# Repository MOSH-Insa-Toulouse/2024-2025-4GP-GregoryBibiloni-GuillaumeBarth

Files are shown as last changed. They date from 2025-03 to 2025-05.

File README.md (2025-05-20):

# 2024-2025-4GP-GregoryBibiloni-GuillaumeBarth

## Projet Capteur Graphite

# Sommaire

- [Contexte](#contexte)
- [Livrables](#livrables)
- [Matériel necéssaire](#matériel-nécessaire)
- [Simulation LTSpice](#simulation-ltspice)
- [Design du PCB via KiCad](#design-du-pcb-via-kicad)
- [Réalisation du Shield](#réalisation-du-shield)
- [Code Arduino](#code-arduino)
- [Application mobile Android via MIT App Inventor](#application-mobile-android-via-mit-app-inventor)
- [Banc de test et analyse](#banc-de-test-et-analyse)
- [Datasheet du capteur graphite](#datasheet-du-capteur-graphite)
- [Conclusion](#conclusion)

---

# Contexte

Ce projet est réalisé dans le cadre de l’UF « du capteur au banc de test » pour les étudiants en quatrième année Génie Physique. Nous nous sommes inspirées de l’article scientifique _Pencil Drawn Strain Gauges and Chemiresistors on Paper_ (Cheng-Wei Lin, Zhibo Zhao, Jaemyung Kim & Jiaxing Huang).
Cet article explique comment faire un capteur résistif à partir de crayon et de papier.

Quand on écrit avec un crayon gris sur du papier, on dépose des couches de graphites qui sont des conducteurs et laisse passer le courant mais avec une résistance. En déformant ce papier, les chaines de graphique sont plus ou moins éloignés et le courant circule plus ou moins facilement ce qui implique une variation de résistance. Ce phénomène fait qu’on peut faire de ce capteur une jauge de contrainte.

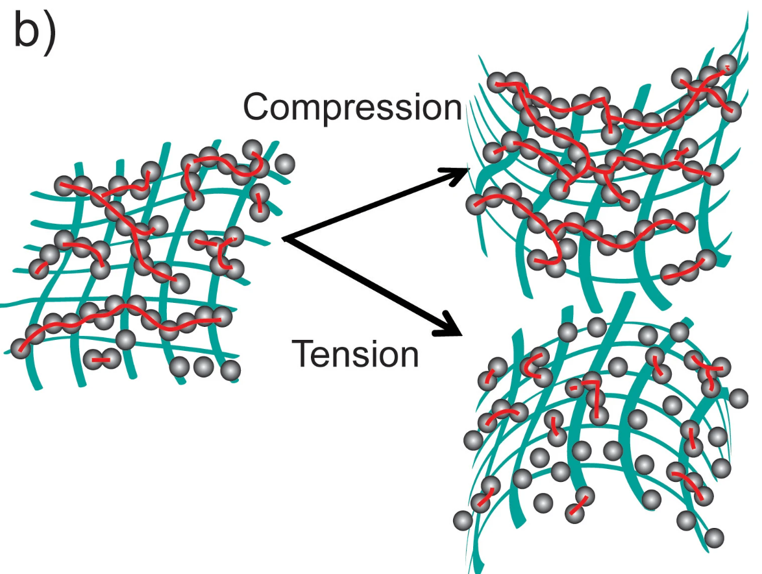
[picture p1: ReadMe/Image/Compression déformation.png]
Schéma 1

_Cette figure vient de l'article cité ci dessus, et montre les chaines de carbone si on effectue une compression ou une flexion du papier. Une compression fait qu'on a des chaines plus proche donc une plus faible valeur de résistance. Pour une flexion on a l'effet contraire_

L’objectif de ce projet est donc de pouvoir réaliser une jauge de contrainte « low-tech » 

---

# Livrables

Voici la liste des livrables :

•	Le Shield PCB branché sur une carte Arduino UNO, intégrant le capteur graphite, un module Bluetooth, un encodeur rotatoire, un potentiomètre numérique, un écran OLED, et un capteur de flexion industriel.

•	Le code Arduino qui permet de contrôler tous les composants et d’acquérir les mesures. (Mesure de résistance, Connection Bluetooth, Affichage de l’OLED, l’encodeur rotatoire et le potentiomètre numérique).

•	L’application Android qui permet d’afficher la valeur de la résistance directement sur son téléphone.

•	La datasheet du capteur en graphite (avec différentes valeurs de crayon).

---

# Matériel nécessaire

Pour concevoir notre dispositif, on a besoin de ces composants :

•	Des résistances : 1 résistance de 1 kΩ, 1 résistance de 10 kΩ, 2 résistances de 100 kΩ, une résistance R2 qui correspond au potentiomètre numérique (le MCP41050) et une résistance de 47 kΩ pour la jauge de contrainte industrielle.

•	Des capacités : 2 capacités de 100 nF et 1 de 1 µF.

•	D’un amplificateur opérationnel : le LTC1050.

•	Un module Bluetooth HC-05.

•	Un encodeur rotatoire ESP32.

•	Un écran OLED 128 * 64.

•	Un flex sensor.

•	Le capteur graphite (connecté avec des pinces croco) fait avec un papier et un crayon.

•	La carte Arduino UNO.

---

# Simulation LTSpice

La résistance interne du capteur graphite est de l’ordre du GΩ donc le courant généré après application de la tension de 5V (Valeur de l’arduino) est faible (de l’ordre du nA). On a besoin de l’amplifier grâce à un montage transimpédance composé d’un amplificateur opérationnel (AOP), le LTC1050, qui peut capter les signaux de faible intensité.

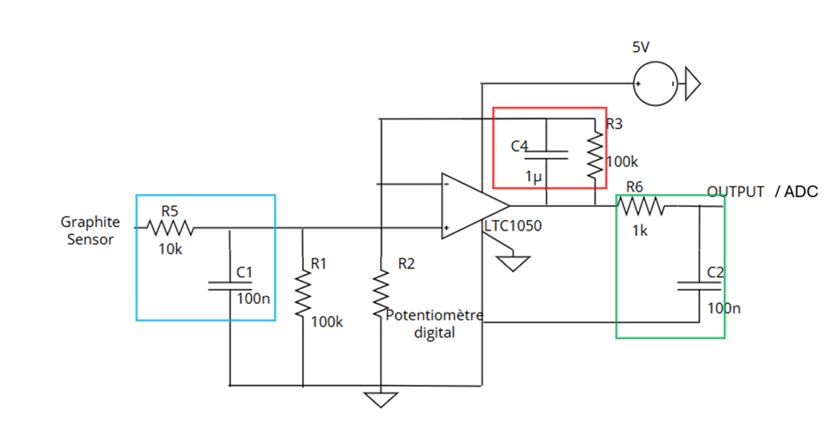
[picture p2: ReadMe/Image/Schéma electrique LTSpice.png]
Schéma 2


Ce montage est composé de 3 filtres afin de limiter le bruit :

•   En rouge, on filtre le 50 Hz du réseau d’électricité

•	En bleu, on filtre le bruit du capteur

•	En vert, on filtre le bruit de l’acquisition de l’Arduino

Voici une simulation sur LTSpice qui montre l'atténuation du bruit en fonction de la fréquence :
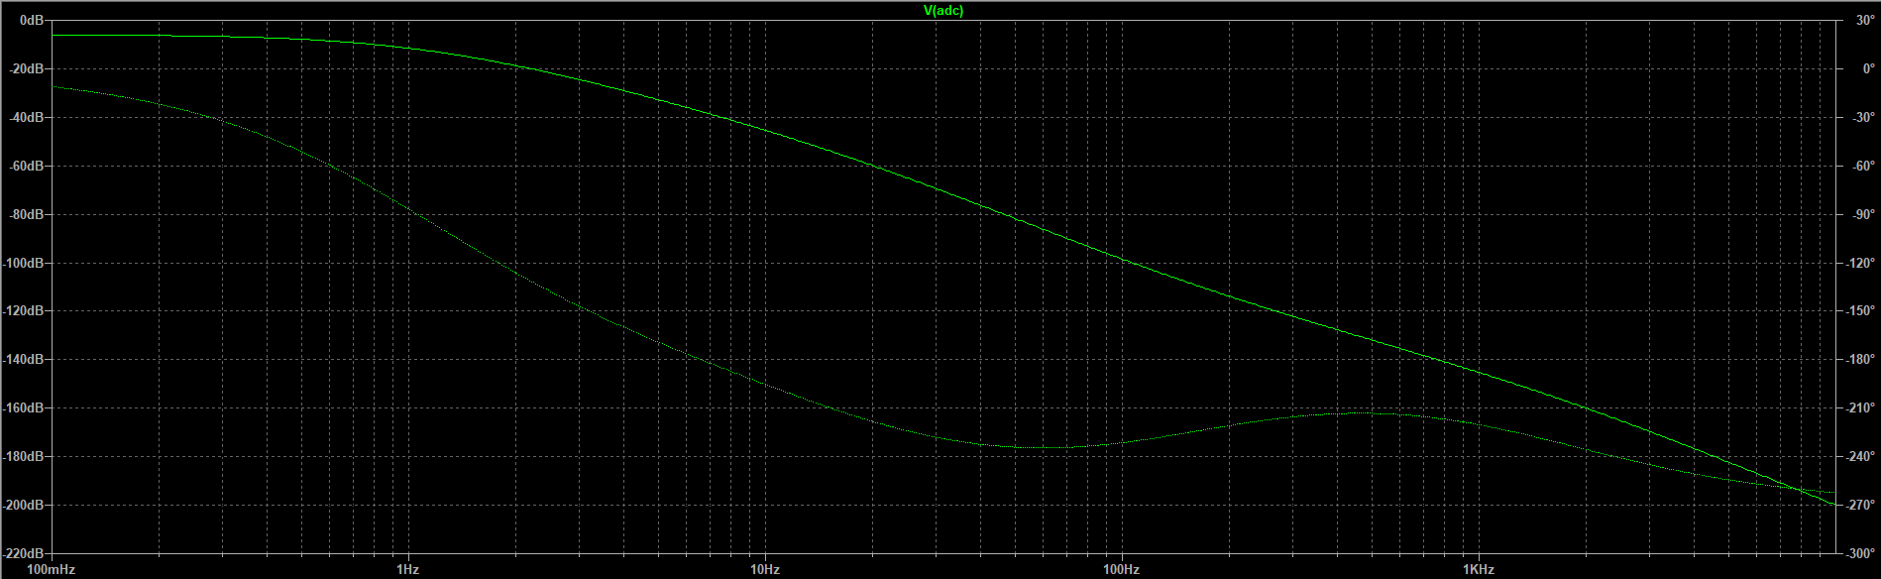
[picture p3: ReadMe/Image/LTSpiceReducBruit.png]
Schéma 2bis


On réduit le 50 Hz de 72 dB environ.

Pour calculer la valeur de la résistance du capteur graphite, la formule est la suivante :

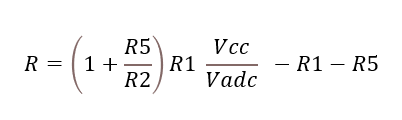
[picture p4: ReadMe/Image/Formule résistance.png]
Schéma 3


Où R2 correspond à la valeur du potentiomètre numérique.

---

# Design du PCB

On a conçu notre PCB via le logiciel KiCad, cela s’est fait en 2 étapes :

La première étape consiste en la réalisation du schématique, donc de créer tous les composants qu’on utilise en leur attribuant des pins, un nom et un modèle 3D. Une fois tous nos composants créés, on rajoute le montage de notre amplificateur transimpédance et on affecte chaque pin de l’Arduino à nos composants et on effectue le câblage entre les différents composants.

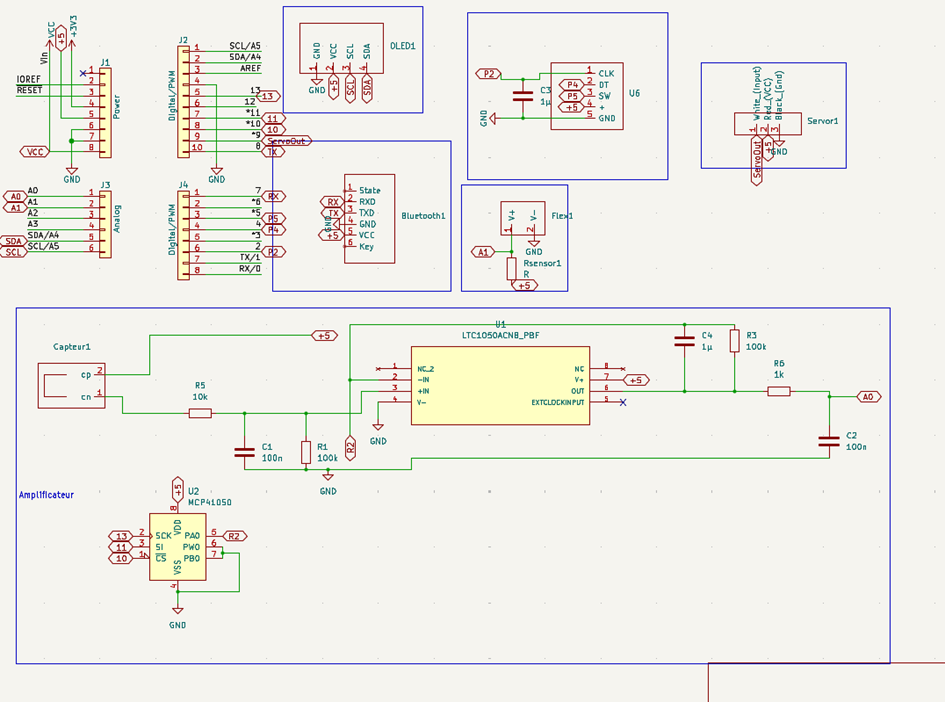
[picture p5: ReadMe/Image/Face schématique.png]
Schéma 4

Ceci est le schéma électrique de l'ensemble de nos composants.

Une fois cela fait, on doit maintenant positionner l'ensemble de nos composants sur le PCB et les relier par la suite. Il faut placer judicieusement les composants sur le PCB afin qu'ils ne se chevauchent pas les uns sur les autres, et qu'ils n'empêchent pas le câblage de l'ensemble des composants. Cette étape nécessite une certaine rigueur afin d'éviter le plus que possible de faire des VIA (trou effectué afin de faire des connexions par-dessus certains routages).

Voici le résultat de notre routage sur notre PCB :

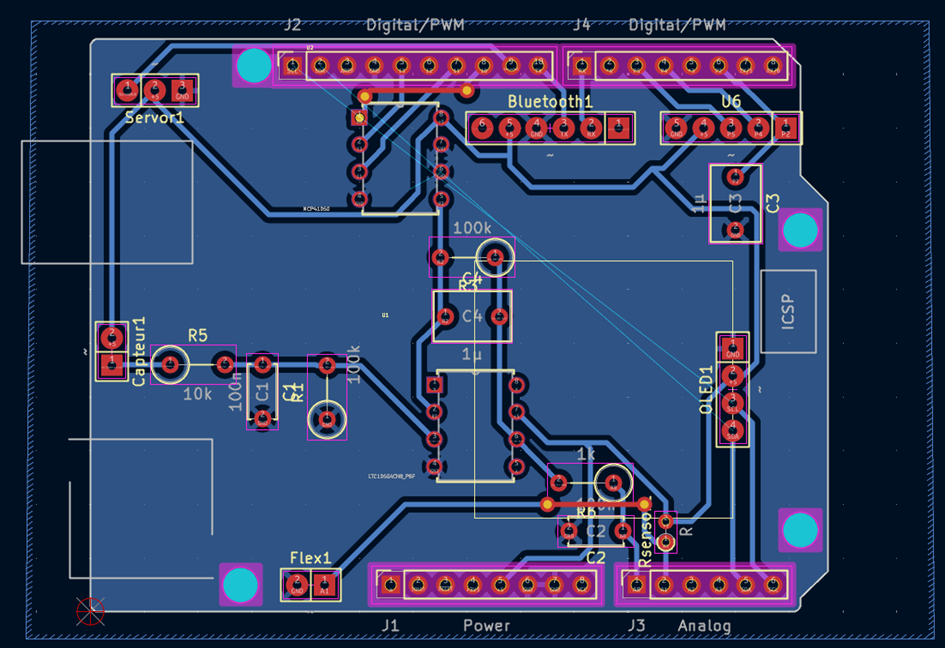
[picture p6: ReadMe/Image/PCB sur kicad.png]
Schéma 5

U6 correspond à l’encodeur rotatoire (et le servor a été mit en plus si on avait besoin d’un servo motor pendant les manipulations).

👉 [Voici le lien pour le KiCad](KiCad/)

---

# Réalisation du Shield

Une fois le PCB réalisé sur KiCaD, on l'a envoyé à Cathy afin qu'elle puisse vérifier que le PCB est correct et prêt à être imprimé. Pour cela, on lui a envoyé notre Gerber, le schéma contenant que le routage de notre carte. Le Gerber sert de masque afin de faire une impression UV sur une couche en cuivre sur la carte en époxy. Une fois cette impression faite, elle a plongé la plaque dans un révélateur qui a retiré les zones non exposées. Enfin un lavage à l'acétone permet d'enlever les dernières impuretés.

Le Gerber :
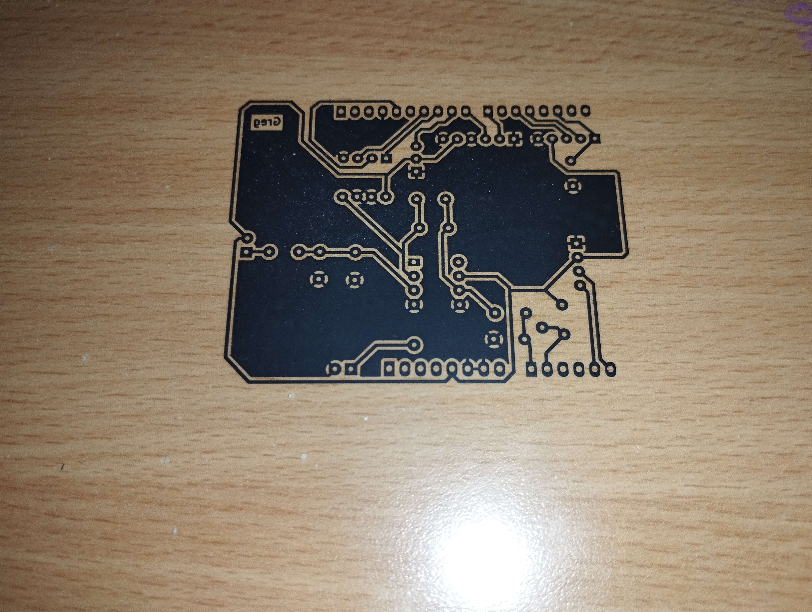
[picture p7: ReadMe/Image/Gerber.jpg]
Schéma 5bis


Il faut par la suite percer des trous sur notre plaque avec un fôret (0.8mm pour les composants et 1mm pour les pins de l’Arduino).

Une fois cette étape effectuée, on place tous nos composants sur notre Shield en les soudants, puis on raccorde le Shield avec la carte Arduino Uno :

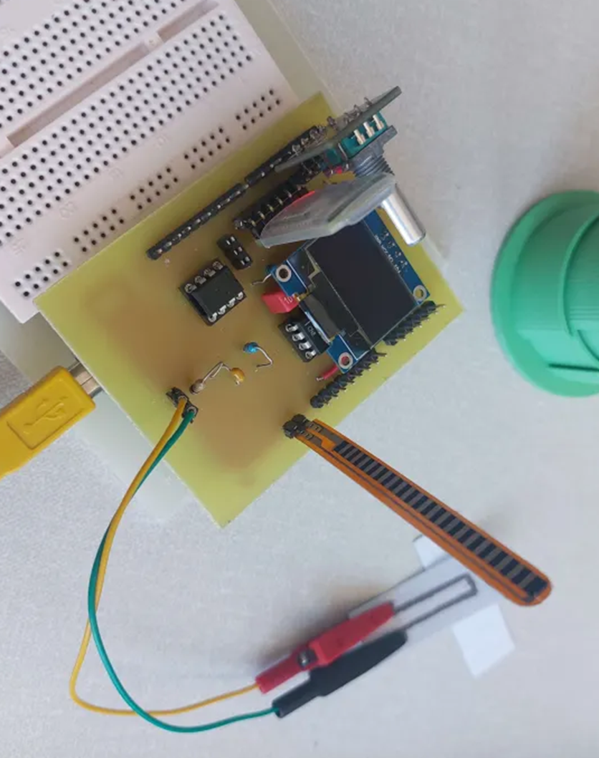
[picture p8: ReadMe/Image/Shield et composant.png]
Schéma 6

---

# Code Arduino

On code maintenant le programme qui permet de faire fonctionner notre système. Dans ce code on peut contrôler un menu qui s’affiche sur l’écran OLED à l’aide de l’encodeur rotatoire. On peut rentrer manuellement la valeur du potentiomètre numérique à l’aide de ce menu, on peut contrôler la connexion Bluetooth et on peut lire la valeur de la résistance liée à la déformation du capteur.

Le code est présent dans notre Git.
👉 [Voici le lien pour le code Arduino](Code%20Arduino/)

---

# Application mobile Android via MIT App Inventor

On a créé l’application grâce au logiciel MIT App Inventor. C’est un APK et il est composé d’une face avant et d’une face arrière : 

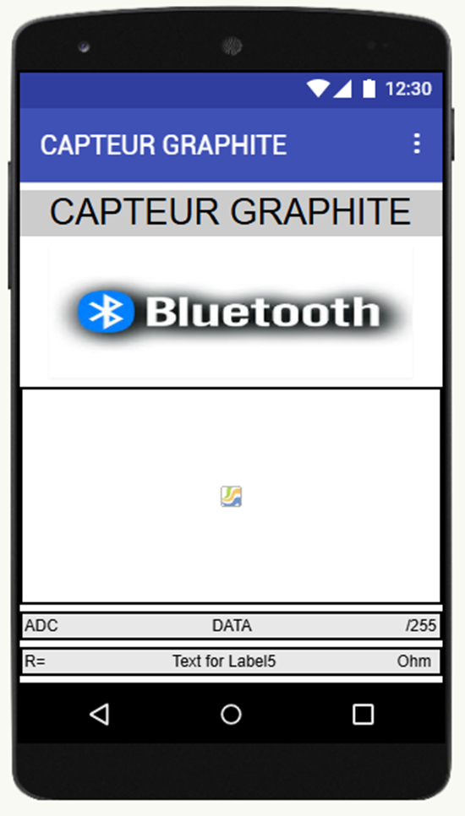
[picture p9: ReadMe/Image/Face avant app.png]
Schéma 7


Ceci est la face avant.

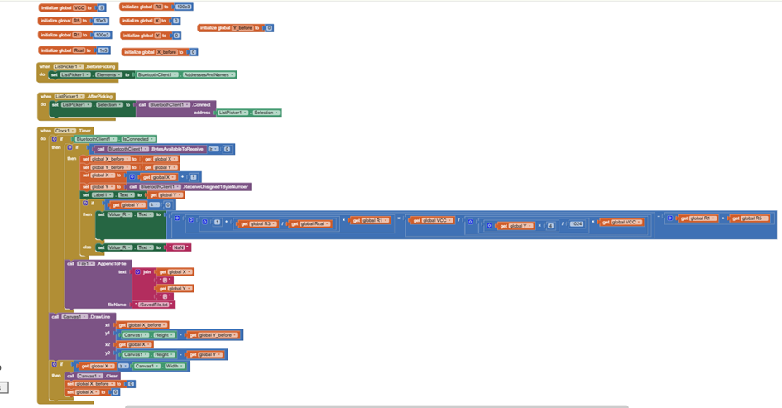
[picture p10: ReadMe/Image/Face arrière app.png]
Schéma 8


Et ceci est la face arrière.

Grâce à cette application, on peut se connecter sur le module Bluetooth et récupérer la valeur de la résistance en fonction de la flexion.

👉 [Voici le lien pour l'application Android (sous forme .aia et .apk)](Application%20Android/)

---

# Banc de test et analyse

On veut faire un banc de test qui permet de calculer la valeur de la résistance du capteur graphite pour différentes valeurs de déformation.
On utilise donc un support qui possèdent différents emplacement qui ont chacun leur propre rayon de courbure.

Le support ressemble à :

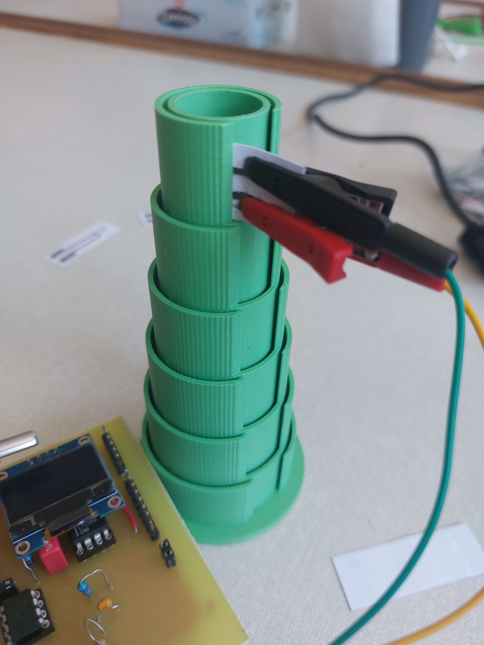
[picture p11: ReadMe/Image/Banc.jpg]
Schéma 9


De haut en bas :

•   Rayon de courbure de 0.045m pour une déformation de 2,11E-3. 

•   Rayon de courbure de 0.04m pour une déformation de 2,38E-3.

•   Rayon de courbure de 0.035m pour une déformation de 2,71E-3.

•   Rayon de courbure de 0.03m pour une déformation de 3,17E-3.

•   Rayon de courbure de 0.025m pour une déformation de 3,80E-3.

•   Rayon de courbure de 0.02m pour une déformation de 4,75E-3.

Voici les résultats obtenus avec une résistance du potentiomètre de 40906 ohms :  

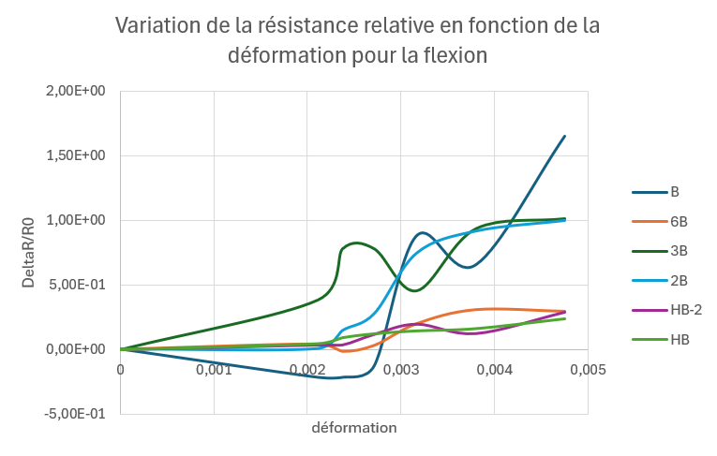
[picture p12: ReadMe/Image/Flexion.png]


Valeur obtenue pour six types de crayons en effectuant une flexion : HB, HB-2, 2B, 3B, 6B et B.
On remarque donc une augmentation de la résistance relative plus on déforme le papier, ce qui était le résultat attendu. Mais le résultat n'est pas linéraire.

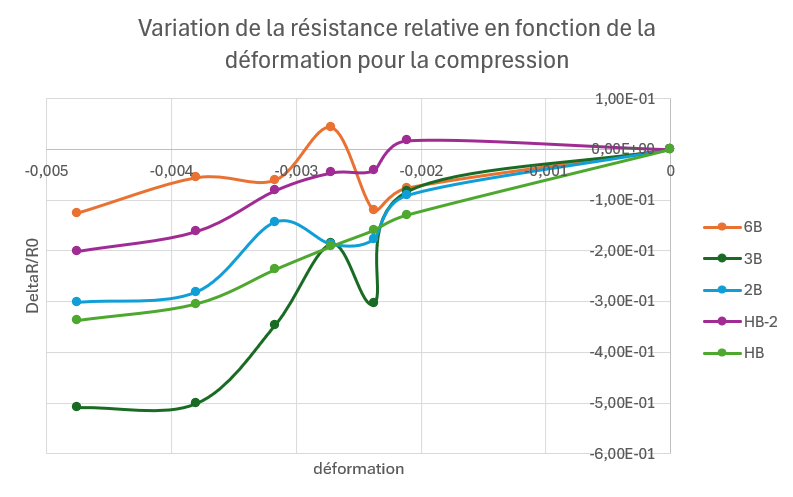
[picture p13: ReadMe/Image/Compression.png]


Valeur obtenue pour cinq types de crayons en effectuant une compression : HB, HB-2, 2B, 3B et 6B.
On remarque donc une diminution de la résistance relative plus on déforme le papier, ce qui était le résultat attendu. Encore une fois le résultat n'est pas linéaire et on n'arrive pas à obtenir des valeurs avec le crayon B.

On a remarqué un défaut pendant nos manipulations, et c'est que le papier s'use très vite et on a souvent besoin de le changer fréquemment afin qu'il soit de nouveau opérationnel. 

---

# Datasheet du capteur graphite

👉 [Voici le lien pour la data sheet](DataSheet/DataSheet.pdf)

---

# Conclusion

En conclusion, ce capteur permet de mesurer des variations de résistance et donner un ordre de grandeur de cette variation. Mais il n'est pas très précis et il s'use facilement. Il ne permet donc pas de remplacer le flex sensor industriel

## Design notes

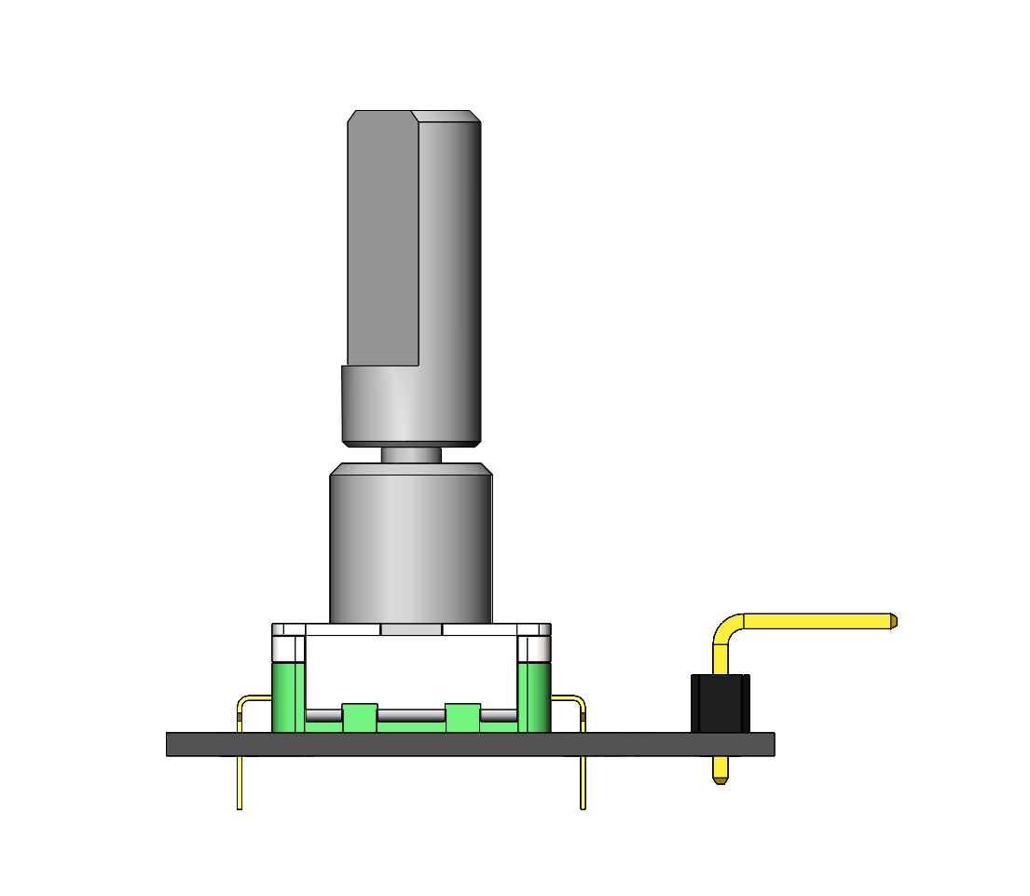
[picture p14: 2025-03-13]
KiCad/3D Models/Rotary encodeur/Rotary Encoder - ODG/image/left.png

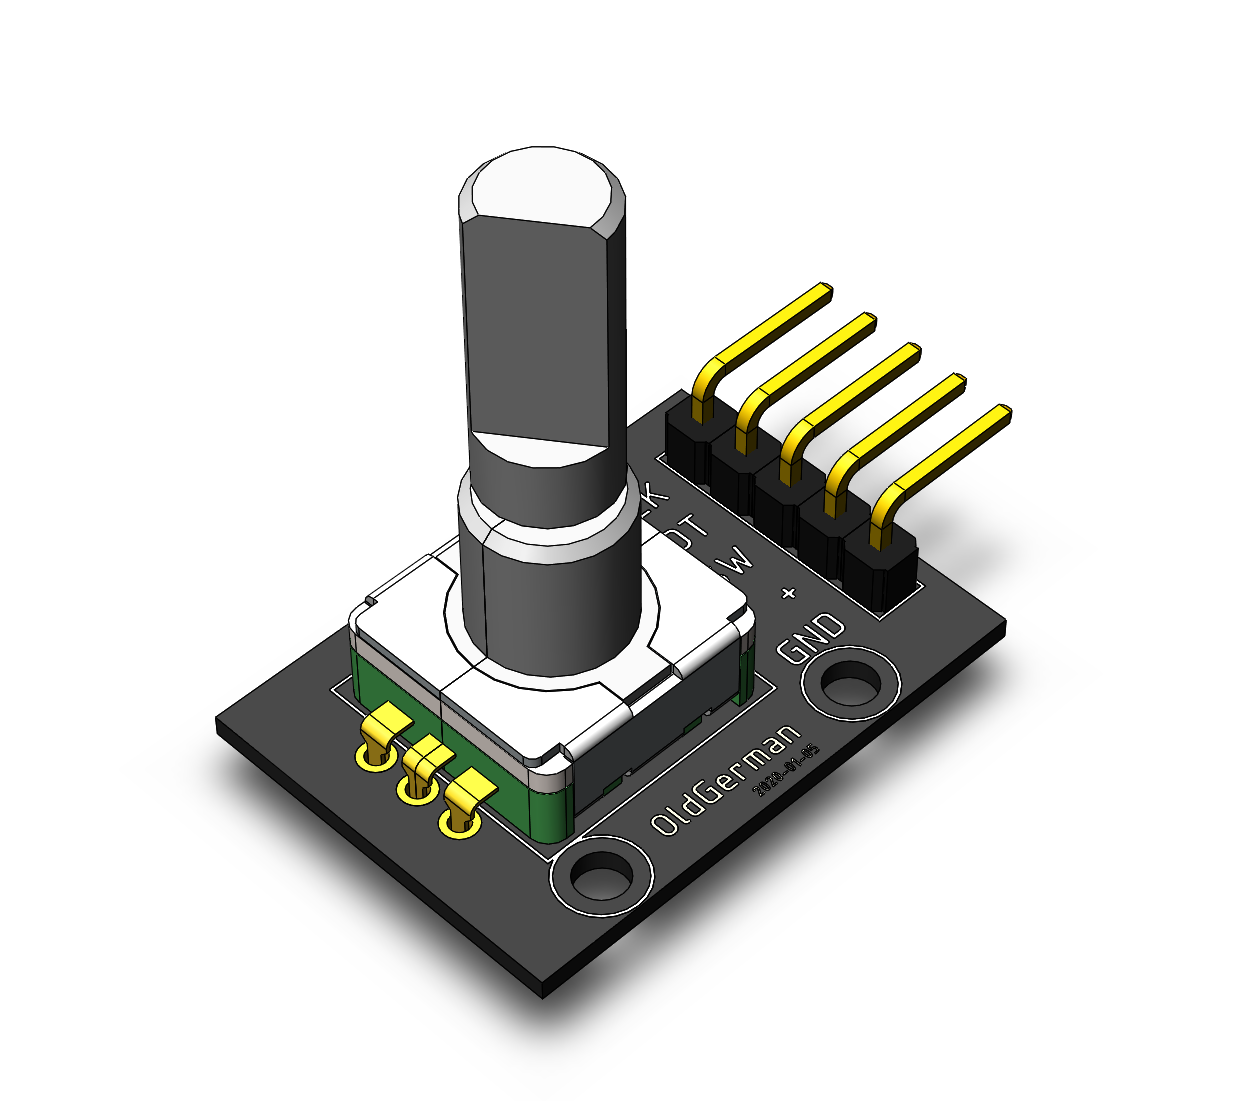
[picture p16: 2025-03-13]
KiCad/3D Models/Rotary encodeur/Rotary Encoder - ODG/image/perspective 1 .png

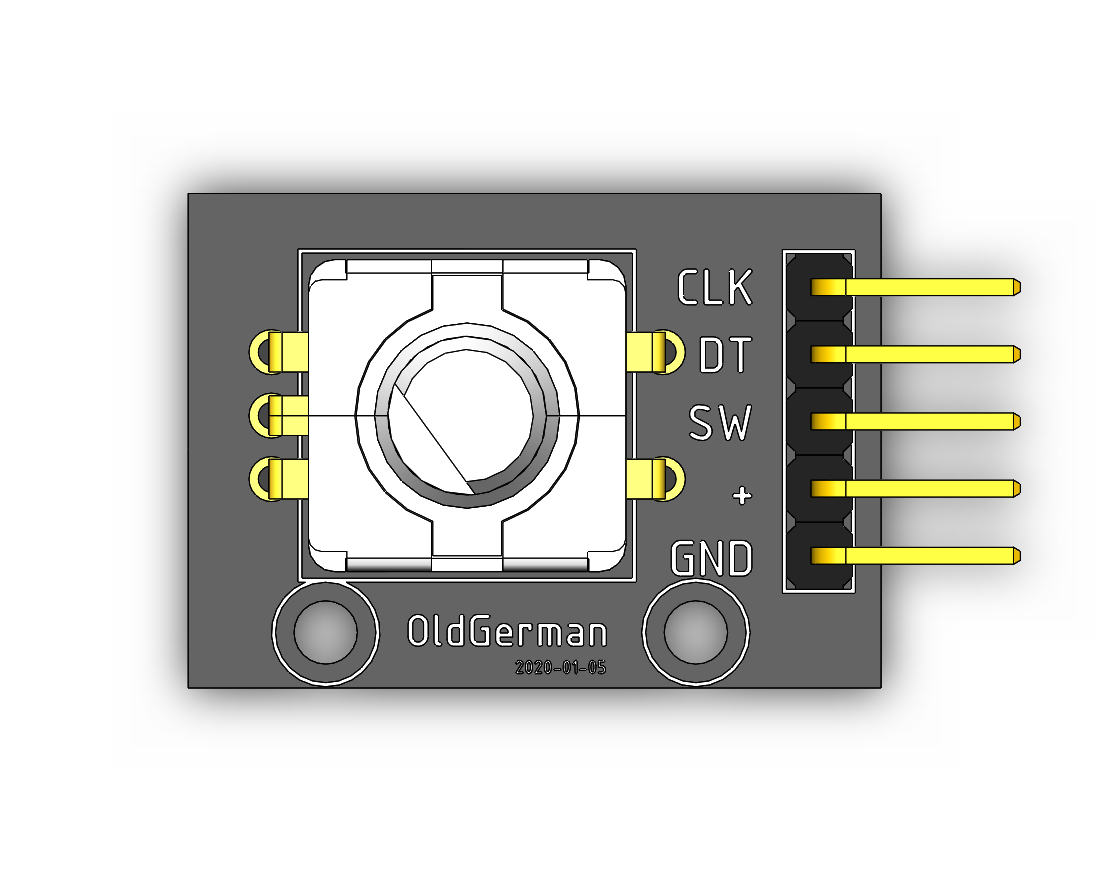
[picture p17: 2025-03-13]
KiCad/3D Models/Rotary encodeur/Rotary Encoder - ODG/image/top.png

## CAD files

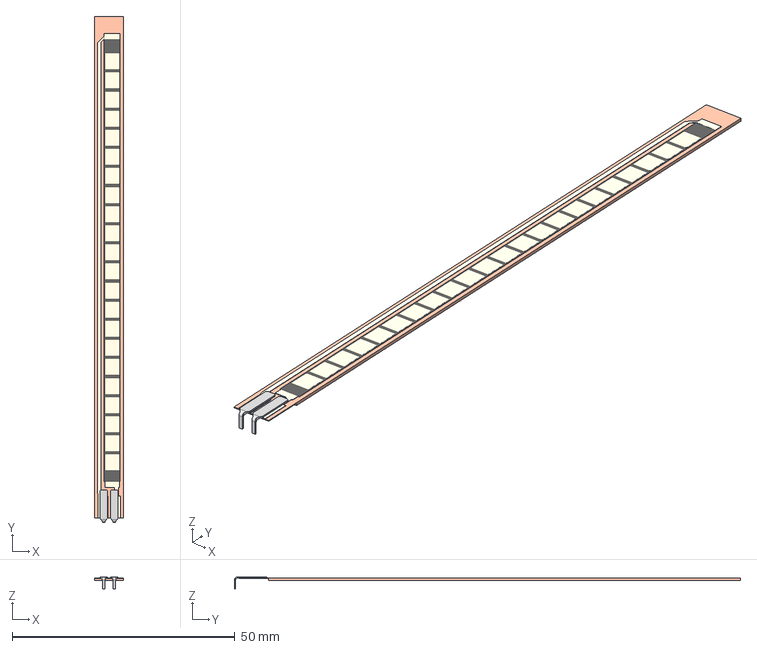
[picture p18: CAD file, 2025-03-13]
KiCad/3D Models/Flex sensor/FS-L-0095-103-ST - Assembly.stp
6.45 x 113.5 x 2.77 mm
FS-L-0095-103-ST - Base
FS-L-0095-103-ST - Top

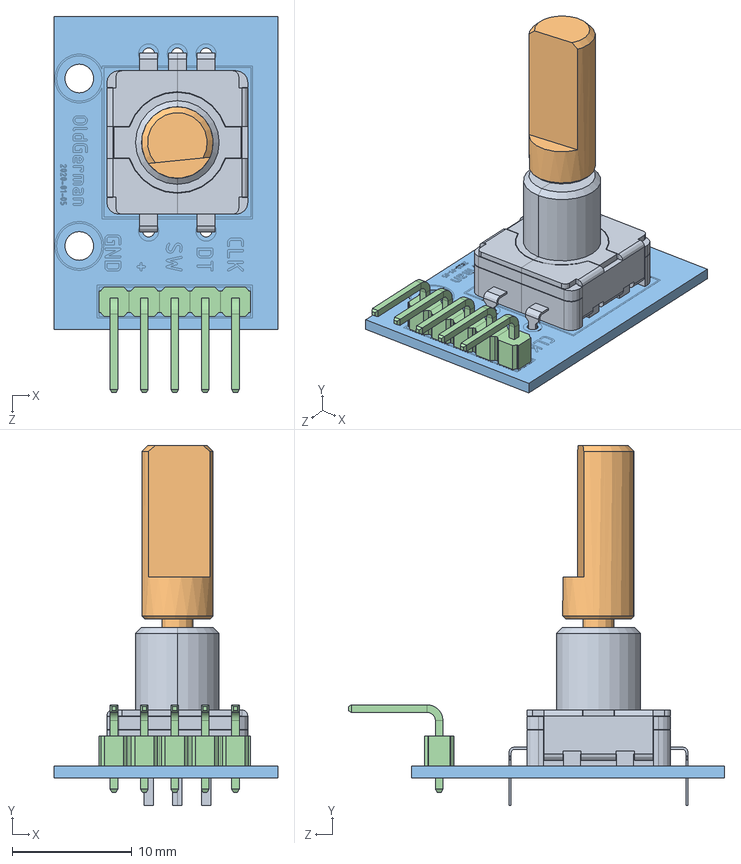
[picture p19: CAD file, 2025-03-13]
KiCad/3D Models/Rotary encodeur/Rotary Encoder - ODG/sw2017 model/KY-040 Rotary Encoder.SLDASM
18.7 x 30.1 x 31.5 mm
Rotary Encoder
D-handle
pcb
2.54 5PIN 90

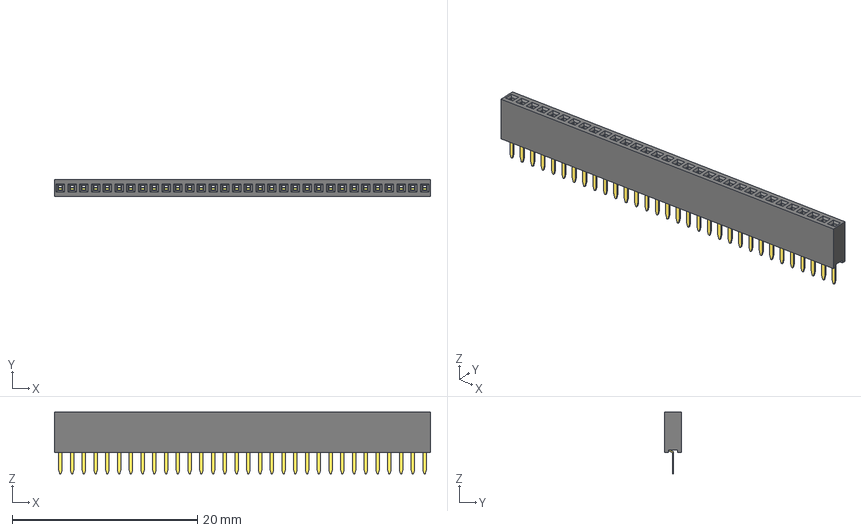
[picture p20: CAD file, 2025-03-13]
KiCad/3D Models/4par1 female header/models3d/PBS1.27/PBS1.27-32.step
40.6 x 1.80 x 6.70 mm

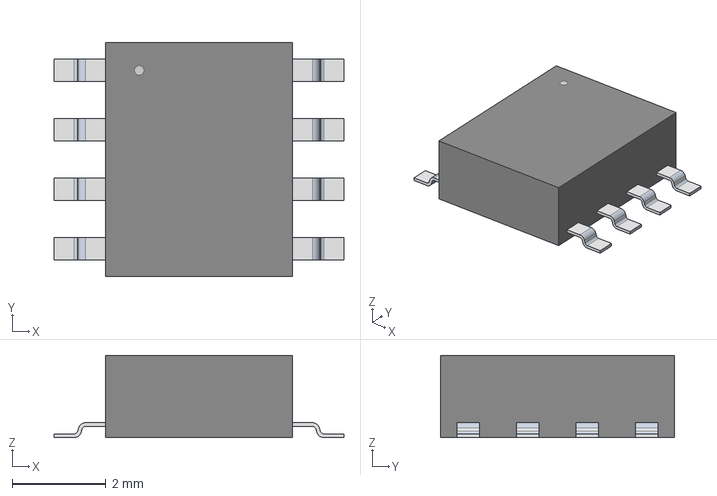
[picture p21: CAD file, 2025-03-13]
KiCad/3D Models/Ampli/SO-8_S_LIT.iges
6.20 x 5.00 x 1.75 mm

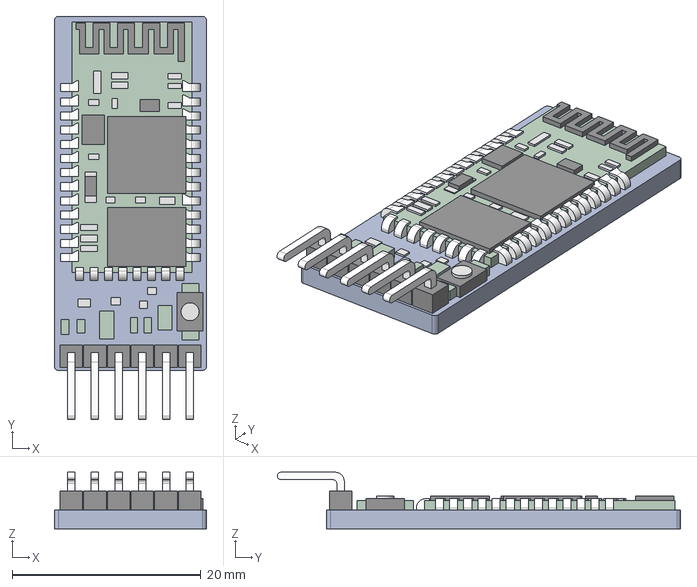
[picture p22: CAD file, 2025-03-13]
KiCad/3D Models/Bluetooth/hc-05-bluetooth-module-2.snapshot.1/HC_05 Blue Tooth Module.stp
16.1 x 42.7 x 6.00 mm

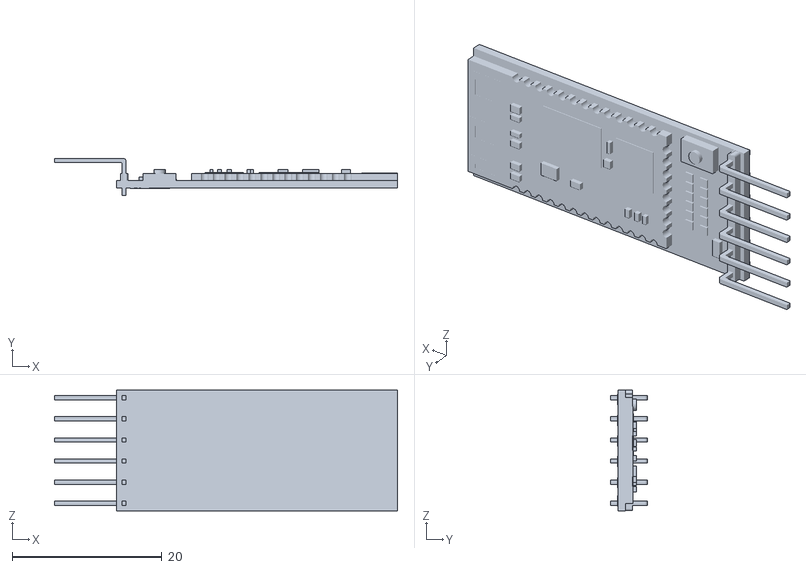
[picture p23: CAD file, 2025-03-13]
KiCad/3D Models/Body2.stl
45.8 x 5.00 x 16.1

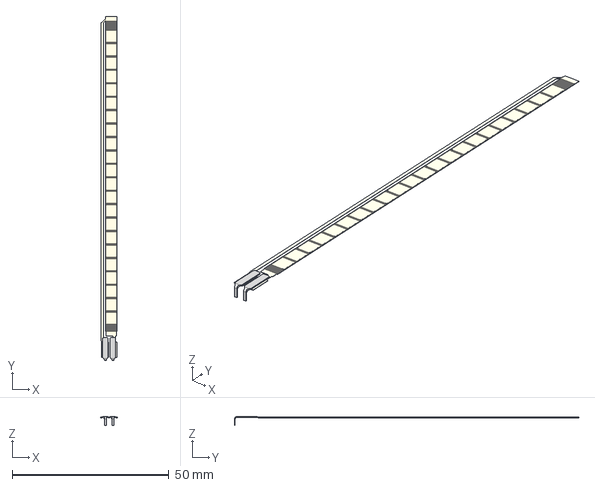
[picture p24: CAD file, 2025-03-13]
KiCad/3D Models/Flex sensor/SolidEdge/FS-L-0095-103-ST - Top - Right.stp
5.17 x 109.7 x 2.77 mm

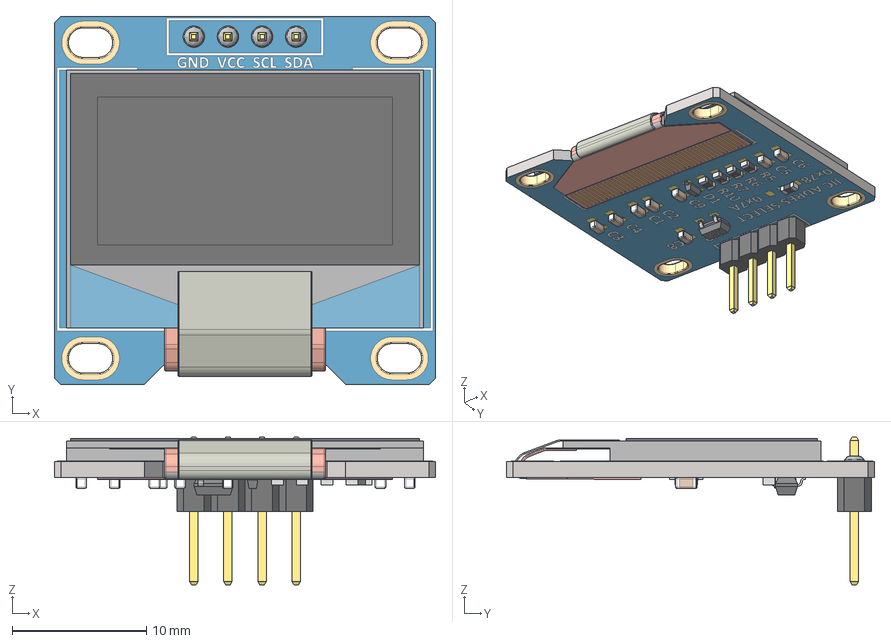
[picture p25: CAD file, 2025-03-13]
KiCad/3D Models/OLED/Pantalla OLED 0.96'' 128x64.stp
28.4 x 27.4 x 11.0 mm
SOT-23_TOR
RES_CR16_MTK_1 x 4
RES_CR16_MTK
SOD323F_DIO

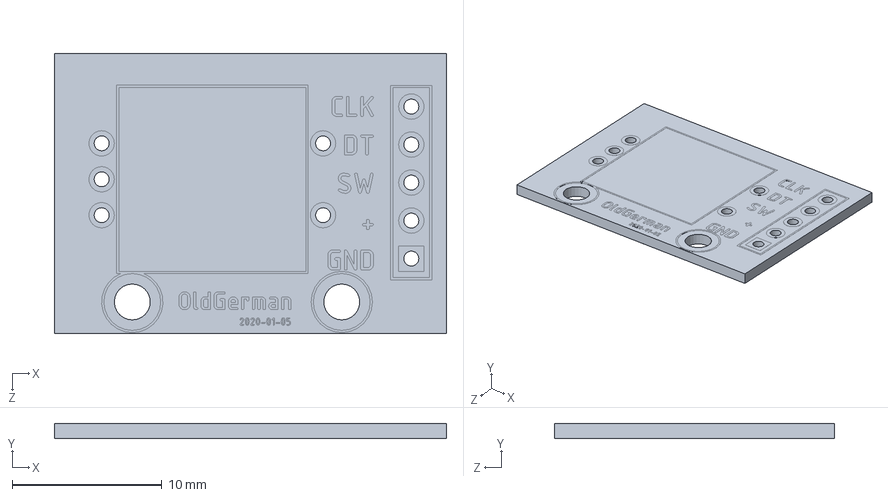
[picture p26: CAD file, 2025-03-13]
KiCad/3D Models/Rotary encodeur/Rotary Encoder - ODG/sw2017 model/pcb.SLDPRT
26.2 x 1.02 x 18.7 mm

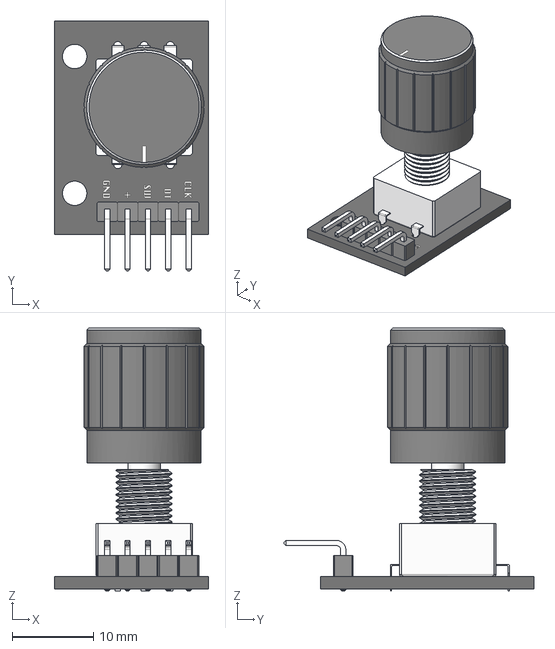
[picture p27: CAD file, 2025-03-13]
KiCad/3D Models/Rotary encodeur/Rotary Encoder - KY-040.step
19.0 x 30.8 x 32.4 mm

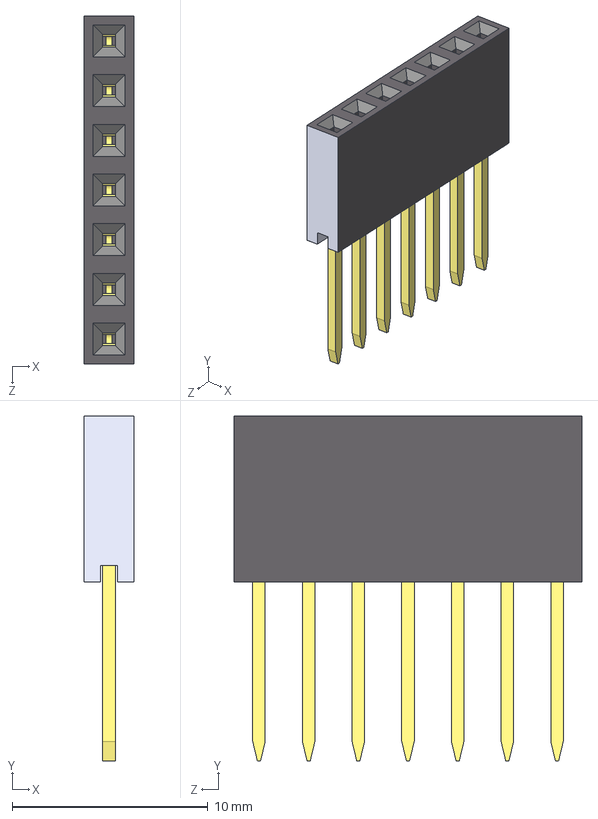
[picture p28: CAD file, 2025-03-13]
KiCad/3D Models/STEP/1x7.STEP
2.54 x 17.6 x 17.8 mm

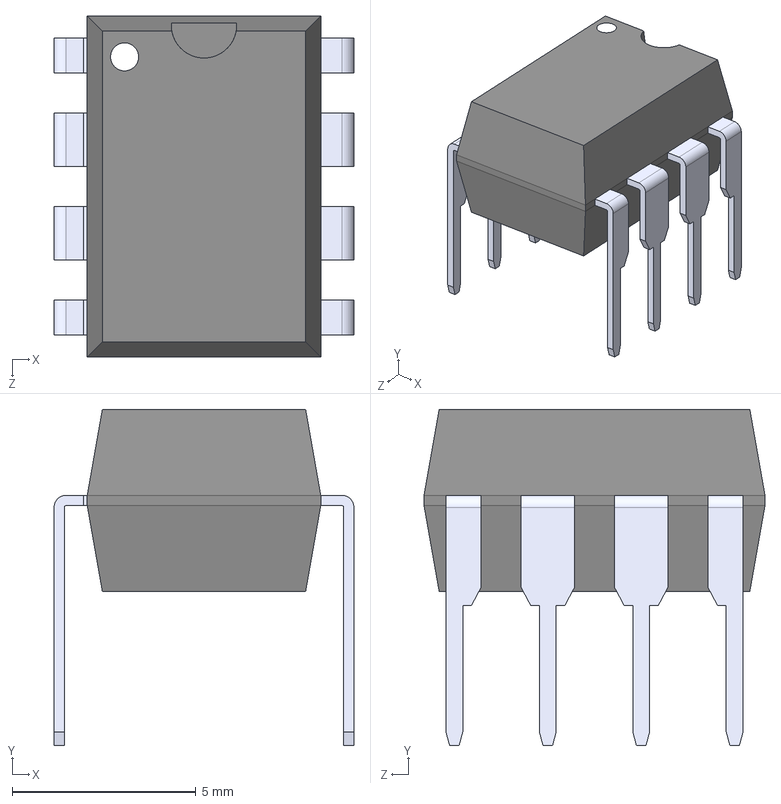
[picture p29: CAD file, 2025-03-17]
KiCad/Librairie_Symbole_Graphite/LTC1050ACN8_PBF.step
8.15 x 9.14 x 9.27 mm

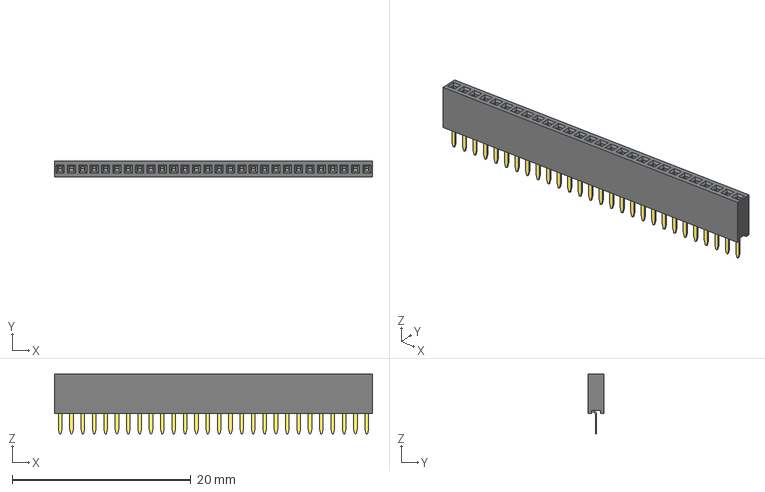
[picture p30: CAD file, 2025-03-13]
KiCad/3D Models/4par1 female header/models3d/PBS1.27/PBS1.27-28.step
35.6 x 1.80 x 6.70 mm

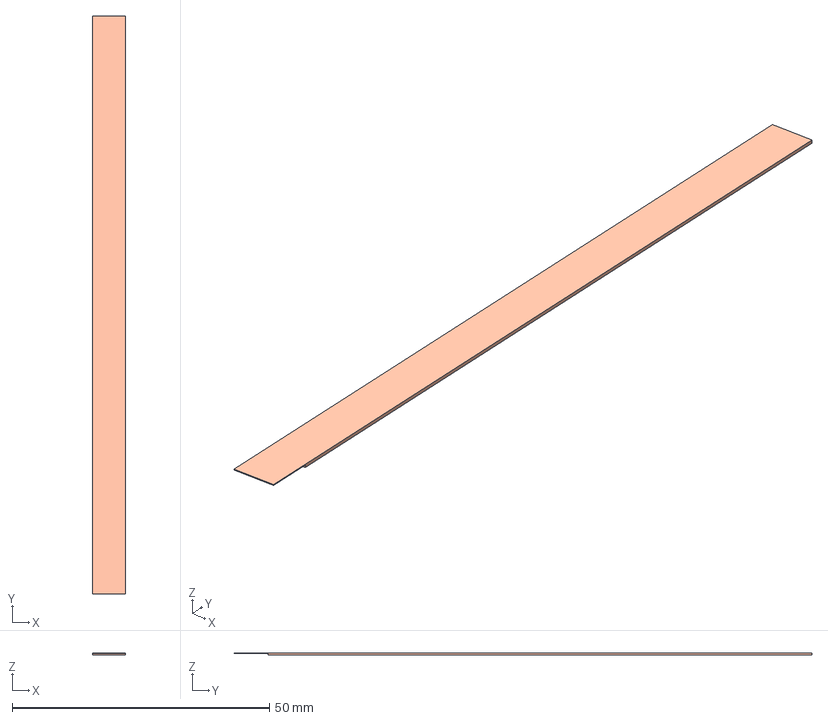
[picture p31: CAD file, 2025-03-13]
KiCad/3D Models/Flex sensor/SolidEdge/FS-L-0095-103-ST - Base.stp
6.45 x 112.4 x 0.483 mm

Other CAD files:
KiCad/3D Models/STEP/1x5.STEP
KiCad/3D Models/4par1 female header/models3d/PBS1.27/PBS1.27-8R.step
KiCad/3D Models/Flex sensor/SolidEdge/FS-L-0095-103-ST - Top.stp
KiCad/3D Models/4par1 female header/models3d/PBS1.27/PBS1.27-1.step
KiCad/3D Models/4par1 female header/models3d/PBS1.27/PBS1.27-10.step
KiCad/3D Models/4par1 female header/models3d/PBS1.27/PBS1.27-10R.step
KiCad/3D Models/4par1 female header/models3d/PBS1.27/PBS1.27-11.step
KiCad/3D Models/4par1 female header/models3d/PBS1.27/PBS1.27-11R.step
KiCad/3D Models/4par1 female header/models3d/PBS1.27/PBS1.27-12.step
KiCad/3D Models/4par1 female header/models3d/PBS1.27/PBS1.27-12R.step
KiCad/3D Models/4par1 female header/models3d/PBS1.27/PBS1.27-13.step
KiCad/3D Models/4par1 female header/models3d/PBS1.27/PBS1.27-13R.step
KiCad/3D Models/4par1 female header/models3d/PBS1.27/PBS1.27-14.step
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

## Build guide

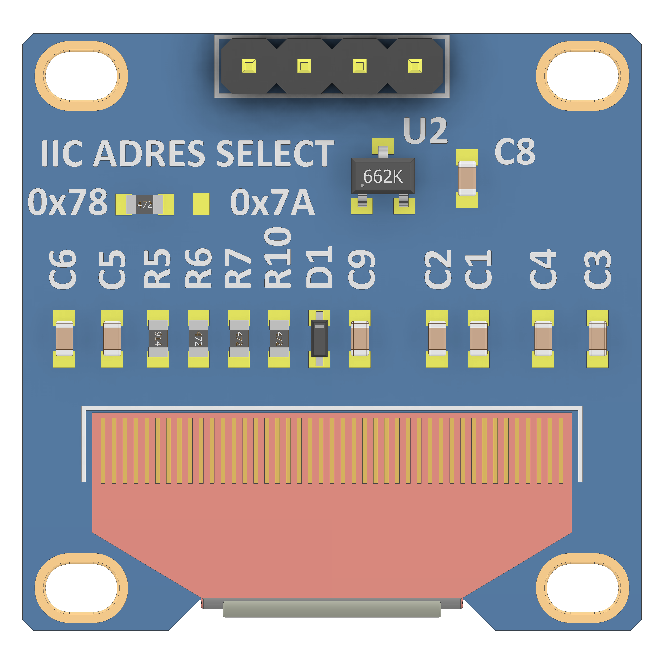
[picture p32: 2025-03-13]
KiCad/3D Models/STEP/Pantalla OLED 0.96'' 128x64 trasera.png

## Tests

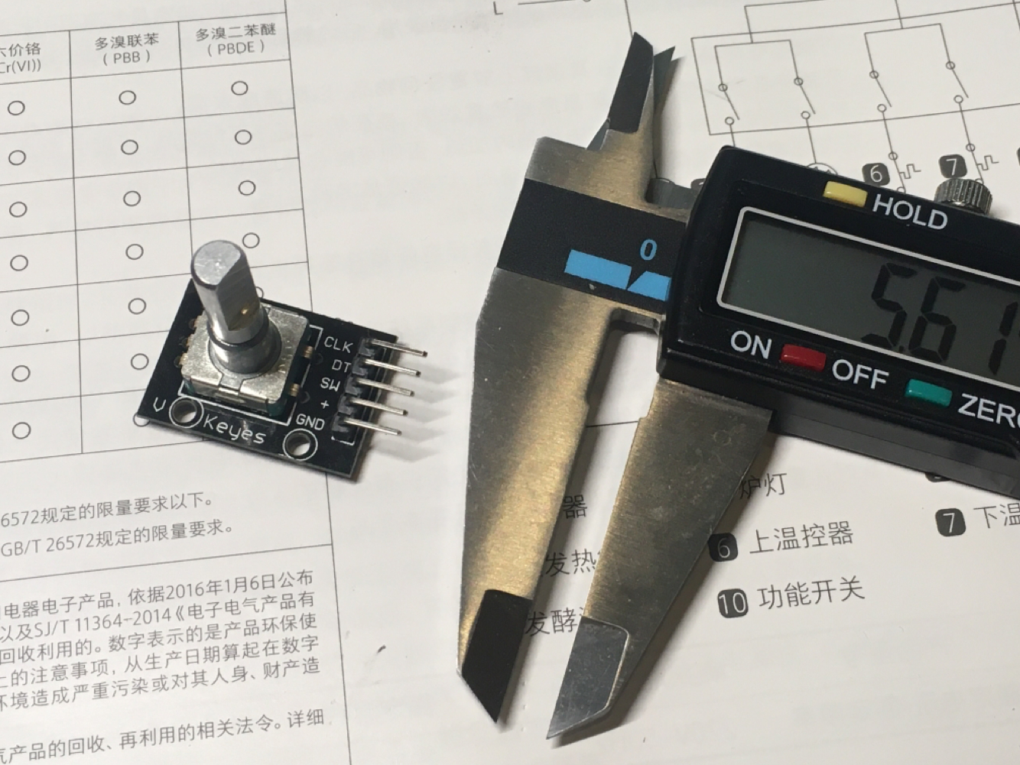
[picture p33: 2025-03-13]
KiCad/3D Models/Rotary encodeur/Rotary Encoder - ODG/image/Measured by hand.png

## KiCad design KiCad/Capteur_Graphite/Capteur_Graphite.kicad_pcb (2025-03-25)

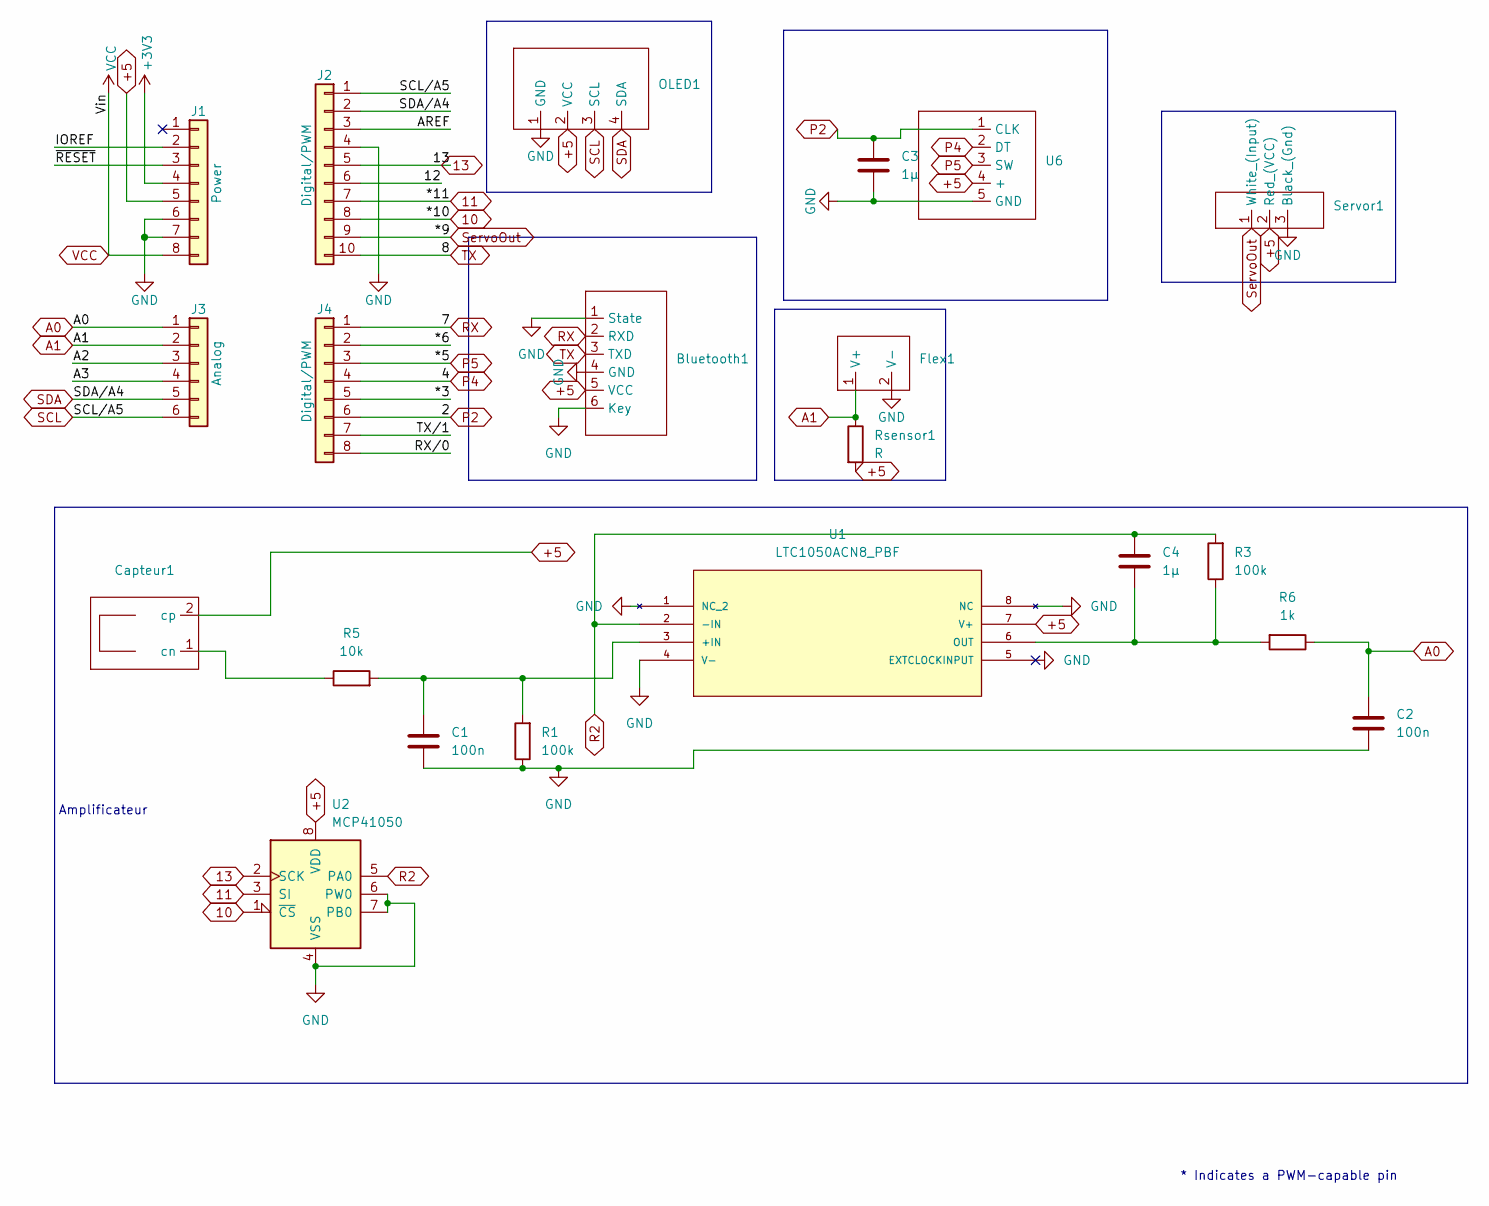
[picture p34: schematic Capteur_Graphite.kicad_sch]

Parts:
Bluetooth1: Bluetooth
C1, C2: 100n; C_Disc_D5.0mm_W2.5mm_P5.00mm
C3, C4: 1µ; C_Rect_L7.0mm_W4.5mm_P5.00mm
Capteur1: CapteurGraph
Flex1: FlexSensor
J1: Power; PinSocket_1x08_P2.54mm_Vertical
J2: Digital/PWM; PinSocket_1x10_P2.54mm_Vertical
J3: Analog; PinSocket_1x06_P2.54mm_Vertical
J4: Digital/PWM; PinSocket_1x08_P2.54mm_Vertical
OLED1: OLED
R1, R3: 100k; R_Axial_DIN0309_L9.0mm_D3.2mm_P5.08mm_Vertical
R5: 10k; R_Axial_DIN0309_L9.0mm_D3.2mm_P5.08mm_Vertical
R6: 1k; R_Axial_DIN0309_L9.0mm_D3.2mm_P5.08mm_Vertical
Rsensor1: R; R_Axial_DIN0309_L9.0mm_D3.2mm_P5.08mm_Vertical
Servor1: ServoMotor
U1: LTC1050ACN8_PBF; LTC1050; MANUFACTURER_PART_NUMBER ltc1050acn8
U2: MCP41050; LTC1050
U6: Rotatoire

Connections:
10: J2.8, U2.1 (~CS)
11: J2.7, U2.3 (SI)
13: J2.5, U2.2 (SCK)
+3V3: J1.4
+5: Bluetooth1.5 (VCC), Capteur1.2 (cp), J1.5, OLED1.2 (VCC), Rsensor1.2, Servor1.2 (Red_(VCC)), U1.7 (V+), U2.8 (VDD), U6.4 (+)
/12: J2.6
/*3: J4.5
/*6: J4.2
/A2: J3.3
/A3: J3.4
/AREF: J2.3
/IOREF: J1.2
/RX/0: J4.8
/TX/1: J4.7
/~RESET: J1.3
A0: C2.1, J3.1, R6.1
A1: Flex1.1 (V+), J3.2, Rsensor1.1
GND: Bluetooth1.1 (State), Bluetooth1.4 (GND), Bluetooth1.6 (Key), C1.2, C2.2, C3.2, Flex1.2 (V-), J1.6, J1.7, J2.4, OLED1.1 (GND), R1.1, Servor1.3 (Black_(Gnd)), U1.1 (NC_2), U1.4 (V-), U1.5 (EXTCLOCKINPUT), U1.8 (NC), U2.4 (VSS), U2.6 (PW0), U2.7 (PB0), U6.5 (GND)
unnamed: Capteur1.1 (cn), R5.1
unnamed: C1.1, R1.2, R5.2, U1.3 (+IN)
unnamed: C4.2, R3.1, R6.2, U1.6 (OUT)
P2: C3.1, J4.6, U6.1 (CLK)
P4: J4.4, U6.2 (DT)
P5: J4.3, U6.3 (SW)
R2: C4.1, R3.2, U1.2 (-IN), U2.5 (PA0)
RX: Bluetooth1.2 (RXD), J4.1
SCL: J2.1, J3.6, OLED1.3 (SCL)
SDA: J2.2, J3.5, OLED1.4 (SDA)
ServoOut: J2.9, Servor1.1 (White_(Input))
TX: Bluetooth1.3 (TXD), J2.10
VCC: J1.8

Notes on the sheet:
Amplificateur
* Indicates a PWM-capable pin

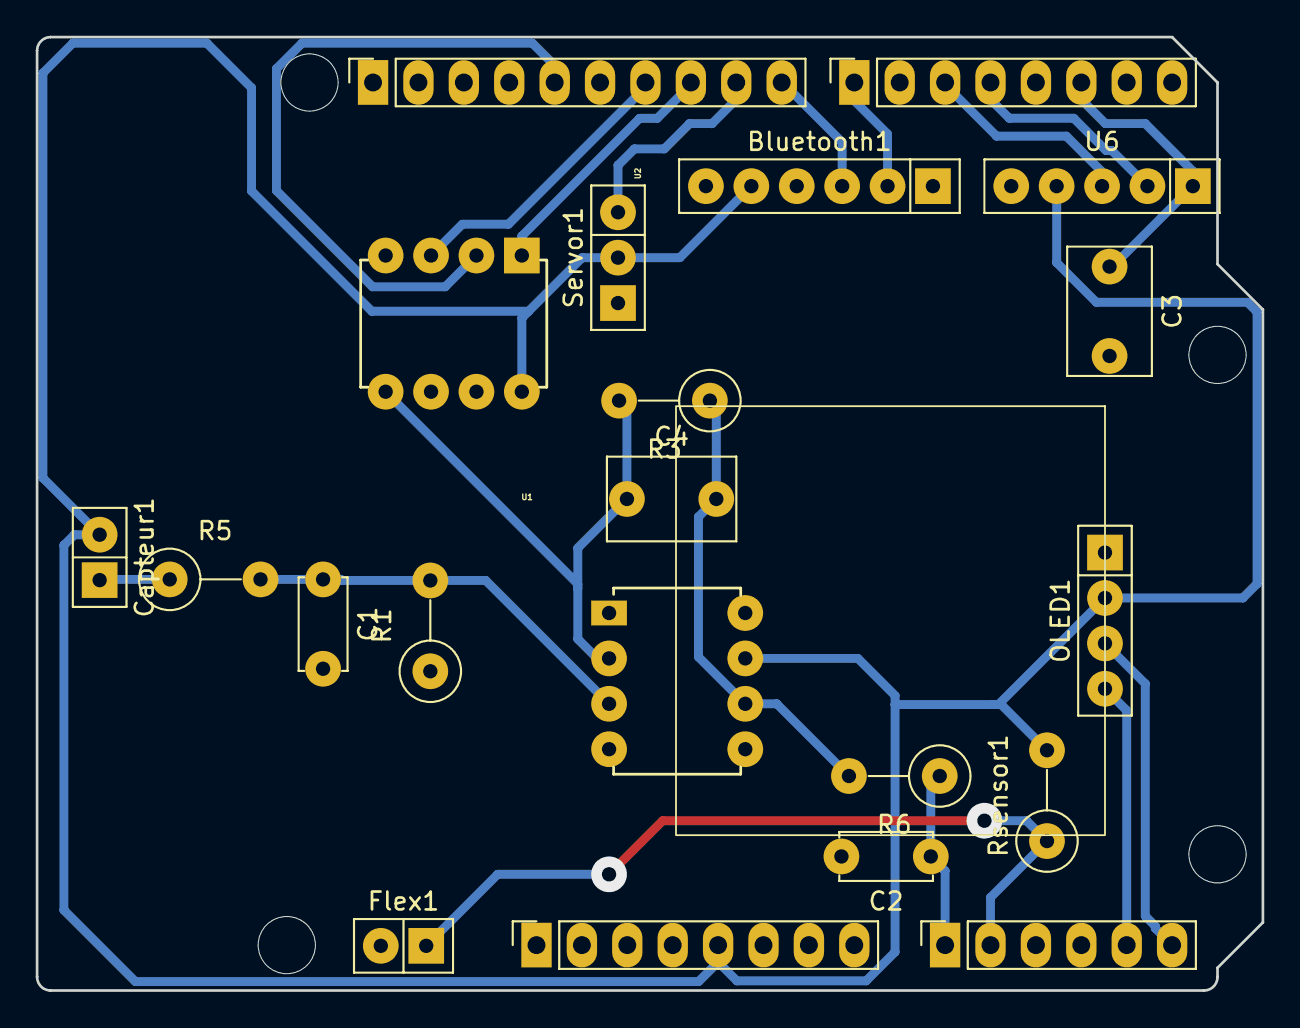
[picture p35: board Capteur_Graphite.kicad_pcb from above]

Board: 2 copper layers, 68.6 x 53.3 mm, 25 parts (0 on the bottom side), 19 nets.

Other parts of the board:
MH1, MH2, MH3, MH4: MountingHole_3.2mm

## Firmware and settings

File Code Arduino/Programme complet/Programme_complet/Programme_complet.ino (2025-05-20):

#include <SPI.h> //librairie du MCP42100 
#include <Adafruit_SSD1306.h> //librairie de l'ecran OLED
#define encoder0PinA  2  //CLK de l'encodeur
#define encoder0PinB  4  //DT de l'encodeur
#define Switch 5 // bouton de l'encodeur

//bluetooth
#include <SoftwareSerial.h>             // Bibliothèque pour gérer la communication avec l'appareil bluetooth
#define rxPin 6                         //Broche 11 en tant que RX, � raccorder sur TX du HC-05
#define txPin 7                         //Broche 10 en tant que RX, � raccorder sur TX du HC-05
#define baudrate 9600                   // baudRate à 9600, identique à celui du moniteur série pour synchroniser la communication
SoftwareSerial mySerial(rxPin, txPin);  // Définition du software serial
int ready = 0;


const int CaptPin = A0; // Pin de lecture de la valeur du capteur

// Parametrage capteur industriel
const int flexPin = A1;      // Pin du capteur industriel
const float VCC = 5;      
const float R_DIV = 10000.0;  // resistance du diviseur de tension
const float flatResistance = 30000.0; // resistance du capteur industriel quand il est plat
const float bendResistance = 1000.0;  // resistance du capteur industriel quand il est à 90 deg


volatile int PosiPot = 0; //regle la valeur initial de l'encodeur
int potPos = 0;

bool valider = false;

bool Pot = false;

bool blue = true;

int Position = 1;

const byte csPin           = 10;      // Pin pour regler la valeur du potentiometre MCP42100 
const int  maxPositions    = 256;     // défini les valeurs max pouvant etre inscrite sur le potentiometre
const long rAB             = 52200;   // 100k pot resistance between terminals A and B, 
                                      // mais pour ajuster au multimètre, je mets 92500
const byte rWiper          = 125;     // 125 ohms pot wiper resistance
const byte pot0            = 0x11;    // pot0 addr // B 0001 0001
const byte pot0Shutdown    = 0x21;    // pot0 shutdown // B 0010 0001

//parametrage de l'ecran OLED
#define nombreDePixelsEnLargeur 128         // Taille de l'écran OLED, en pixel, au niveau de sa largeur
#define nombreDePixelsEnHauteur 64          // Taille de l'écran OLED, en pixel, au niveau de sa hauteur
#define brocheResetOLED         -1          // Reset de l'OLED partagé avec l'Arduino (d'où la valeur à -1, et non un numéro de pin)
#define adresseI2CecranOLED     0x3C        // Adresse de "mon" écran OLED sur le bus i2c (généralement égal à 0x3C ou 0x3D)
Adafruit_SSD1306 ecranOLED(nombreDePixelsEnLargeur, nombreDePixelsEnHauteur, &Wire, brocheResetOLED);

void setPotWiper(int addr, int pos) {
  char ResASCII[10];
  ecranOLED.clearDisplay();                                   // Effaçage de l'intégralité du buffer
  ecranOLED.setTextSize(1);                   // Taille des caractères (1:1, puis 2:1, puis 3:1)
  ecranOLED.setCursor(0, 0);

  pos = constrain(pos, 0, 255);            // limite les parametre du potentiometre entre 0 et 255
  digitalWrite(csPin, LOW);                // Activation de l'ecriture
  SPI.transfer(addr);                      // positionne le potentiometre à la valeur defini
  SPI.transfer(pos);
  digitalWrite(csPin, HIGH);               // Desactivation de l'ecriture

  // ecrit la resistance du potentiometre resistance utiliser par notre circuit
  long resistanceWB = ((rAB * pos) / maxPositions ) + rWiper;
  ecranOLED.setTextColor(SSD1306_WHITE); //Calcul de la valeur de la resistance correspondant à la position     
  ecranOLED.print("Position: ");
  ecranOLED.println(pos);
  ecranOLED.println(" Resistance correspondante: ");
  ecranOLED.print(resistanceWB);
  ecranOLED.println(F(" ohms"));
  ecranOLED.print(analogRead(CaptPin)*(5.0/1023.0)*1000.0);
  ecranOLED.println(" mV");
  ecranOLED.setTextColor(SSD1306_BLACK, SSD1306_WHITE);
  ecranOLED.println("Retour");
  dtostrf(resistanceWB, 5, 2, ResASCII);
    if (blue){
    
    mySerial.write(ResASCII); // Envoyer sur le port bluetooth la valeur acquise
  }

}

void setup() { 
  Serial.begin (9600); // defini le Baud rate de l'arduina pour la lecture
  
  pinMode(encoder0PinA, INPUT); // Configuration de la PIN CLK de l'encodeur pour permetre la lecture
  digitalWrite(encoder0PinA, HIGH);

  pinMode(encoder0PinB, INPUT); // Configuration de la PIN DT de l'encodeur pour permetre la lecture
  digitalWrite(encoder0PinB, HIGH); 

  digitalWrite(Switch, HIGH);         //Permet de traiter le switch comme un vrai bouton avec une résistance pull Up
  
  attachInterrupt(0,Encoder, RISING); //Creer une interruption pour activer la lecture de la postion de l'encodeur. Pourrait etre remplacer par une fonction de detection de front montant mais cela alourdi le code de manière inutile
  
  digitalWrite(csPin, HIGH);        // Desactivation par defaut de l'écriture du potentiometre
  pinMode(csPin, OUTPUT);           // Configure la Pin du potentiometre en mode ecriture
  SPI.begin(); // librairie permettant de manipuler les adresse du potentiometre. Pourrait surement être alléger mais cela necessiterait de regarder plus en détaille le MCP42100 
  ecranOLED.begin(SSD1306_SWITCHCAPVCC, adresseI2CecranOLED);

  pinMode(flexPin, INPUT);

  pinMode(rxPin,INPUT);
  pinMode(txPin,OUTPUT);

  Serial.begin(baudrate);
  mySerial.begin(baudrate); // Initialiser le port bluetooth
} 

void loop(){
  
  Control_OLED();
  Bouton();
}

void Encoder() {
  if (digitalRead(encoder0PinA)==HIGH && digitalRead(encoder0PinB)==HIGH) {
    
    if (Pot){
    PosiPot++;
    }
    else if(!valider){
    Position++;
    }  
      
  } else if (digitalRead(encoder0PinA)==HIGH && digitalRead(encoder0PinB)==LOW) {
    if (Pot){
    PosiPot--;
    } 
    else if(!valider){
      Position--;      
    }     
  }
  //Permet de faire boucler les valeurs entre 4 et 1. Cela permet de faire un menu déroulant
  if(Position > 4){
    Position = 1;
  }else if(Position < 1){
    Position = 4;
  }

  if(PosiPot >= 256){
    PosiPot = 0;
  }else if(PosiPot < 0){
    PosiPot = 255;
  }
  Pot = false;
}

void Bouton() {
  if (digitalRead(Switch)==LOW) {
    valider=!valider;
    delay(500);
    Serial.println(valider);
  }
  if (valider & Position == 3){
    blue = !blue;
  }
}


void Menu_OLED(){
  //initialisation ecran
    ecranOLED.clearDisplay();                                   // Effaçage de l'intégralité du buffer
    ecranOLED.setTextSize(1);                   // Taille des caractères (1:1, puis 2:1, puis 3:1)
    ecranOLED.setCursor(0, 0);  
    switch(Position){
      case 1: 
      ecranOLED.setTextColor(SSD1306_BLACK, SSD1306_WHITE);
      ecranOLED.println(F("Graphite "));
      ecranOLED.setTextColor(SSD1306_WHITE);
      ecranOLED.println(F("Industriel "));
      ecranOLED.println(F("Bluetooth "));
      ecranOLED.println(F("Potentio "));
      break;
      case 2:
      ecranOLED.setTextColor(SSD1306_WHITE);
      ecranOLED.println(F("Graphite "));      
      ecranOLED.setTextColor(SSD1306_BLACK, SSD1306_WHITE);
      ecranOLED.println(F("Industriel "));
      ecranOLED.setTextColor(SSD1306_WHITE);
      ecranOLED.println(F("Bluetooth "));
      ecranOLED.println(F("Potentio "));
      break;
      case 3:
      ecranOLED.setTextColor(SSD1306_WHITE);
      ecranOLED.println(F("Graphite "));
      ecranOLED.println(F("Industriel "));
      ecranOLED.setTextColor(SSD1306_BLACK, SSD1306_WHITE);
      ecranOLED.println(F("Bluetooth "));
      ecranOLED.setTextColor(SSD1306_WHITE);
      ecranOLED.println(F("Potentio "));
      break;
      case 4:
      ecranOLED.setTextColor(SSD1306_WHITE);
      ecranOLED.println(F("Graphite "));
      ecranOLED.println(F("Industriel "));
      ecranOLED.println(F("Bluetooth "));
      ecranOLED.setTextColor(SSD1306_BLACK, SSD1306_WHITE);
      ecranOLED.println(F("Potentio "));
      break;
    }                               
    ecranOLED.display();                            // Transfert le buffer à l'écran
    delay(200);
  }


void Graph_OLED(){
    setPotWiper(pot0, PosiPot);
    Serial.println(analogRead(CaptPin));
    ecranOLED.display();
}

void Flex_OLED(){
  ecranOLED.clearDisplay();                                   // Effaçage de l'intégralité du buffer
  ecranOLED.setTextSize(1);                   // Taille des caractères (1:1, puis 2:1, puis 3:1)
  ecranOLED.setCursor(0, 0);
   int ADCflex = analogRead(flexPin);
  float Vflex = ADCflex * VCC / 1023.0;
  float Rflex = R_DIV * (VCC / Vflex - 1.0);
  Serial.println("Resistance: " + String(Rflex) + " ohms");

  // Use the calculated resistance to estimate the sensor's bend angle:
  float angle = map(Rflex, flatResistance, bendResistance, 0, 90.0);
  ecranOLED.setTextColor(SSD1306_WHITE);  
  ecranOLED.println("Bend: " + String(angle) + " degrees");
  ecranOLED.setTextColor(SSD1306_BLACK, SSD1306_WHITE);
  ecranOLED.println("Retour");
  ecranOLED.display();

  delay(500);
}

void Blue_OLED(){
  ecranOLED.clearDisplay();                                   // Effaçage de l'intégralité du buffer
  ecranOLED.setTextSize(1);                   // Taille des caractères (1:1, puis 2:1, puis 3:1)
  ecranOLED.setCursor(0, 0);
  ecranOLED.setTextColor(SSD1306_WHITE);  
  if(blue){
    ecranOLED.println("BLUETOOTH ON");
  }
  else{
    ecranOLED.println("BLUETOOTH OFF");
  }

  ecranOLED.setTextColor(SSD1306_BLACK, SSD1306_WHITE);
  ecranOLED.println("Retour");
  ecranOLED.display();
}

void Pot_OLED(int addr, int pos){
  Pot = true;
  ecranOLED.clearDisplay();                                   // Effaçage de l'intégralité du buffer
  ecranOLED.setTextSize(1);                   // Taille des caractères (1:1, puis 2:1, puis 3:1)
  ecranOLED.setCursor(0, 0);

  PosiPot = constrain(PosiPot, 0, 255);            // limite les parametre du potentiometre entre 0 et 255
  digitalWrite(csPin, LOW);                // Activation de l'ecriture
  SPI.transfer(addr);                      // positionne le potentiometre à la valeur defini
  SPI.transfer(PosiPot);
  digitalWrite(csPin, HIGH);               // Desactivation de l'ecriture

  // ecrit la resistance du potentiometre resistance utiliser par notre circuit
  long resistanceWB = ((rAB * PosiPot) / maxPositions ) + rWiper;
  ecranOLED.setTextColor(SSD1306_WHITE); //Calcul de la valeur de la resistance correspondant à la position     
  ecranOLED.print("Position: ");
  ecranOLED.println(PosiPot);
  ecranOLED.println(" Resistance correspondante: ");
  ecranOLED.print(resistanceWB);
  ecranOLED.println(" ohms");
  ecranOLED.setTextColor(SSD1306_BLACK, SSD1306_WHITE);
  ecranOLED.println("Retour");
  ecranOLED.display();
  

}

void Control_OLED(){
  ecranOLED.clearDisplay(); 
if (valider){
  switch(Position){
    case 1:
  Graph_OLED();
  break;
  case 2:
  Flex_OLED();
  break;
  case 3:
  Blue_OLED();
  break;
  case 4:
  Pot_OLED(pot0, potPos);
  break;
  }
  }
  else{
    Menu_OLED();
  }
}

void code_blue(){

}

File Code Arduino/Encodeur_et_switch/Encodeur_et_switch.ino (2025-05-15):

/* Read a rotary encoder with interrupts
   Encoder hooked up with common to GROUND,    encoder0PinA to pin 2, encoder0PinB to pin 4
   it doesn't matter which encoder pin you use for A or B  
*/ 

#define encoder0PinA  2  //CLK Output A Do not use other pin for clock as we are using interrupt
#define encoder0PinB  4  //DT Output B
#define Switch 5 // Switch connection if available

volatile int encoderPos = 0;
volatile int Push = 0;
const byte csPin           = 10;      // MCP42100 chip select pin
const int  maxPositions    = 256;     // wiper can move from 0 to 255 = 256 positions
const long rAB             = 52200;   // 100k pot resistance between terminals A and B, 
                                      // mais pour ajuster au multimètre, je mets 92500
const byte rWiper          = 125;     // 125 ohms pot wiper resistance
const byte pot0            = 0x11;    // pot0 addr // B 0001 0001
const byte pot0Shutdown    = 0x21;    // pot0 shutdown // B 0010 0001

void setPotWiper(int addr, int pos) {
  pos = constrain(pos, 0, 255);            // limit wiper setting to range of 0 to 255
  digitalWrite(csPin, LOW);                // select chip
  SPI.transfer(addr);                      // configure target pot with wiper position
  SPI.transfer(pos);
  digitalWrite(csPin, HIGH);               // de-select chip

  // print pot resistance between wiper and B terminal
  long resistanceWB = ((rAB * pos) / maxPositions ) + rWiper;
  Serial.print("Wiper position: ");
  Serial.print(pos);
  Serial.print(" Resistance wiper to B terminal: ");
  Serial.print(resistanceWB);
  Serial.println(" ohms");
}

void setup() { 
  Serial.begin (9600);
  
  pinMode(encoder0PinA, INPUT); 
  digitalWrite(encoder0PinA, HIGH);       // turn on pullup resistor

  pinMode(encoder0PinB, INPUT); 
 digitalWrite(encoder0PinB, HIGH);       // turn on pullup resistor
 digitalWrite(Switch, HIGH);            //Permet de traiter le switch comme un vrai bouton avec une résistance pull Up
 attachInterrupt(0,Encoder, RISING);
 digitalWrite(csPin, HIGH);        // chip select default to de-selected
  pinMode(csPin, OUTPUT);           // configure chip select as output
  SPI.begin();


  Serial.println("start");                // a personal quirk
} 

void loop(){
  //do some stuff here - the joy of interrupts is that they take care of themselves
  Bouton();
  Serial.println ("test");
  Serial.println (encoderPos); 
  Serial.println ("ACAB");
  Serial.println (Push);//Angle = (360 / Encoder_Resolution) * encoder0Pos
  delay(500);
}

void Encoder() {
  if (digitalRead(encoder0PinA)==HIGH && digitalRead(encoder0PinB)==HIGH) {
    encoderPos++;
  } else if (digitalRead(encoder0PinA)==HIGH && digitalRead(encoder0PinB)==LOW) {
    encoderPos--;
  }
}
void Bouton() {
  if (digitalRead(Switch)==LOW) {
    Push=6;
  }
}

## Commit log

2025-02-19 Ajout de ma todo liste
2025-03-13 Organisation du projet sur Github
    [1x10.STEP, 1x2.STEP, 1x4.STEP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]
2025-03-13 Clear PCB
    [Capteur_Graphite.kicad_pcb, Capteur_Graphite.kicad_sch]
2025-03-13 Schematique propre
    [Capteur_Graphite.kicad_pcb, Capteur_Graphite.kicad_sch]
2025-03-13 Fin de séance du 13 mars
    [Capteur_Graphite.kicad_pcb, Capteur_Graphite.kicad_sch]
2025-03-14 PCB fini
    [Capteur_Graphite.kicad_pcb, Capteur_Graphite.kicad_sch]
2025-03-17 ajout lib symbol + retouche kicad_pcb
    [Capteur_Graphite.kicad_pcb, LTC1050ACN8_PBF.step]
2025-03-17 Version Final du PCB + Gerber
    [Capteur_Graphite.kicad_pcb, Capteur_Graphite.kicad_sch, SO-8_S_LIT.iges]
2025-03-25 Version Final corrigée du PCB
    [Capteur_Graphite.kicad_pcb, Capteur_Graphite.kicad_sch]
2025-03-25 Finale 3 GND connecté
    [Capteur_Graphite.kicad_pcb]
2025-03-25 Version Finale 4 le retour
    [Capteur_Graphite.kicad_pcb]
2025-03-25 repositionement 3D
    [Capteur_Graphite.kicad_pcb]
2025-05-15 Rajout de texte
2025-05-15 Ajout du code arduino
    [1x10.STEP, 1x2.STEP, 1x4.STEP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]
2025-05-15 Rajout de l'application
2025-05-15 Rajout dans le test simple de la conversion en mV et pas en byt

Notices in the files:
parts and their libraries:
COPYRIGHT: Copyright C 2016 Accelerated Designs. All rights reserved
